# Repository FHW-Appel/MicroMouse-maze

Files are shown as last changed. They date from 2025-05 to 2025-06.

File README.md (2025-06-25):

# Half-Size Micromouse Maze – Projektüberblick

Dieses Projekt beinhaltet die Konstruktion und Fertigung eines Labyrinths (Maze) für ein Half-Size Micromouse-System. Grundlage ist das offizielle Regelwerk der *UK Micromouse and Robotics Society (UKMARS)*, welches in Europa als Standard für Wettbewerbe gilt.

Das Maze besteht aus modularen Zellen (je **9 × 9 cm**), standardisierten Wänden, Pfosten, Bodenplatten und Verbindungselementen. Alle Maße und Farben entsprechen den Vorgaben des UKMARS Half-Size Regelwerks.

Die Konstruktion erfolgte in *Fusion 360*, die einzelnen Komponenten wurden per **3D-Druck** aus PLA gefertigt. Das Maze ist vollständig zerlegbar und kann in unterschiedlichen Layouts aufgebaut werden.

---

## Hinweise zur Nutzung

Das Repository enthält die jeweils **aktuelle Version** aller STL-Dateien. Es werden **keine Versionsnummern** wie `_1.0.stl`, `_2.0.stl` usw. verwendet. Alle Dateien sind direkt einsatzbereit und eindeutig benannt.

### Projektstruktur

- **Bodenplattenmodule/**  
  STL-Dateien für die Bodenplatten, auf denen Wände und Pfosten montiert werden.

- **Stopfenmodule/**  
  STL-Dateien für die Eckpfosten (Blindstopfen), die an den Gitterpunkten zwischen den Zellen eingesetzt werden.

- **Verbindungsmodule/**  
  STL-Dateien für Verbindungselemente zur Fixierung von Bodenplatten und Wänden.

- **Wandmodule/**  
  STL-Dateien für die standardisierten Innenwände des Maze.

- **Projekt-Infos/**  
  Enthält diese Datei (`README.md`) mit allgemeinen Informationen zum Projekt und zur Nutzung.

---

Bei Bedarf können die STL-Dateien direkt in gängige Slicer-Software importiert und für den 3D-Druck vorbereitet werden

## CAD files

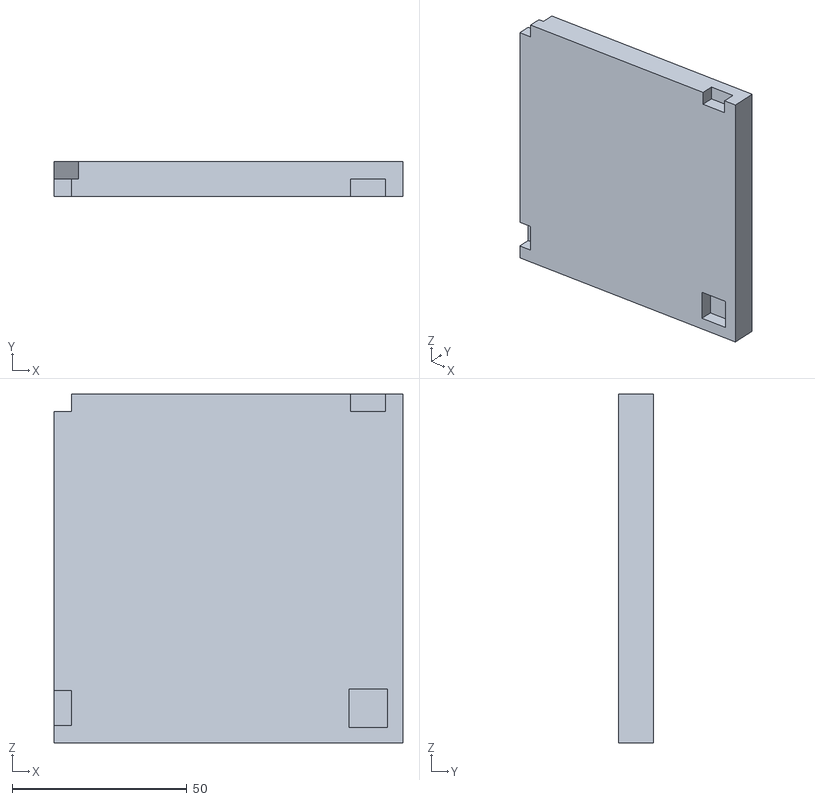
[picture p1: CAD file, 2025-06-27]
Bodenmudule/Boden_Ecke.stl
100.0 x 10.0 x 100.0

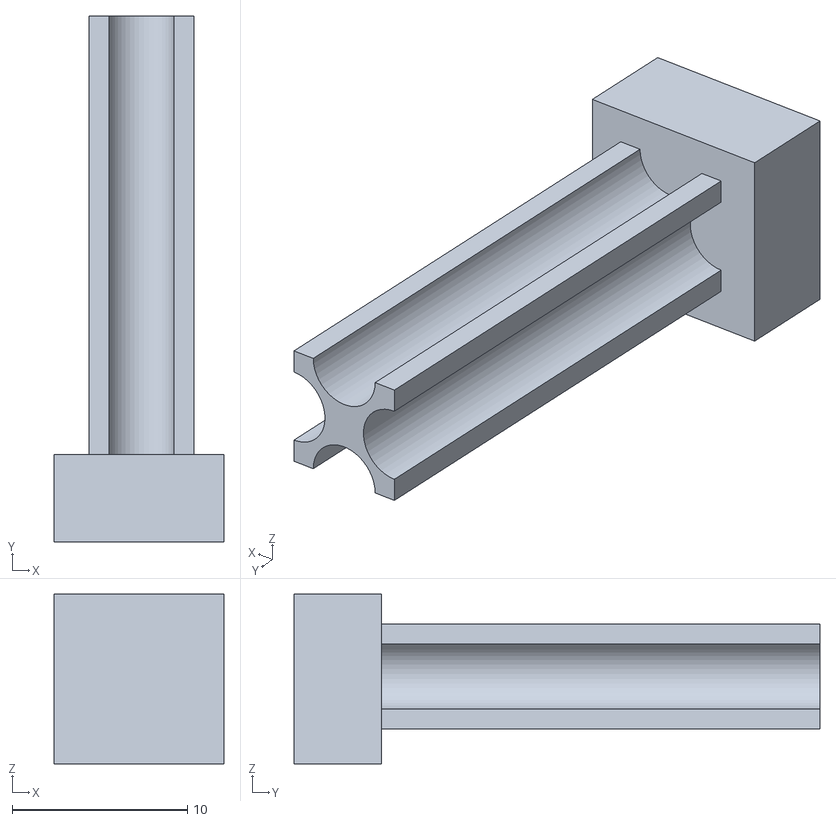
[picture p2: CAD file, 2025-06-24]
Stopfenmodul/Stopfen.stl
9.70 x 30.0 x 9.70

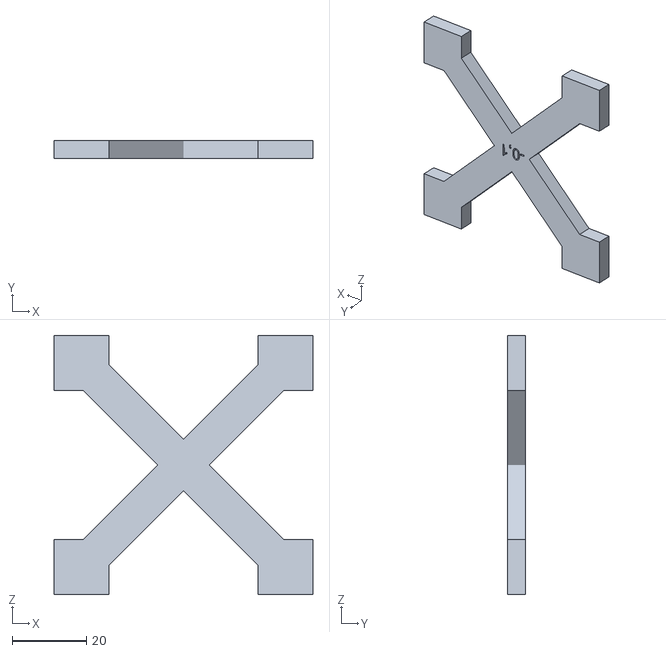
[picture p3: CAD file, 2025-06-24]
Verbindungsmodul/Boden_Kreuzverbindung.stl
69.8 x 4.80 x 69.8

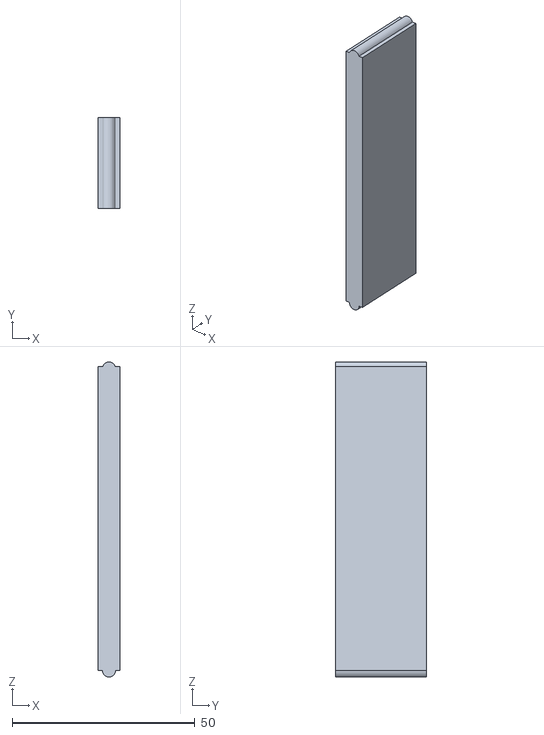
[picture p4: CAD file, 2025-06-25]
Wandmodule/Wand.stl
6.00 x 25.0 x 86.1

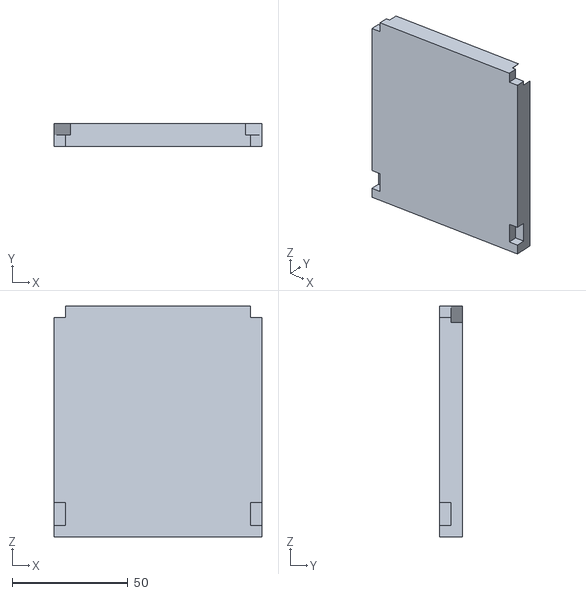
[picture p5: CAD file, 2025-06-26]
Bodenmudule/Boden_Kante.stl
90.0 x 10.0 x 100.0

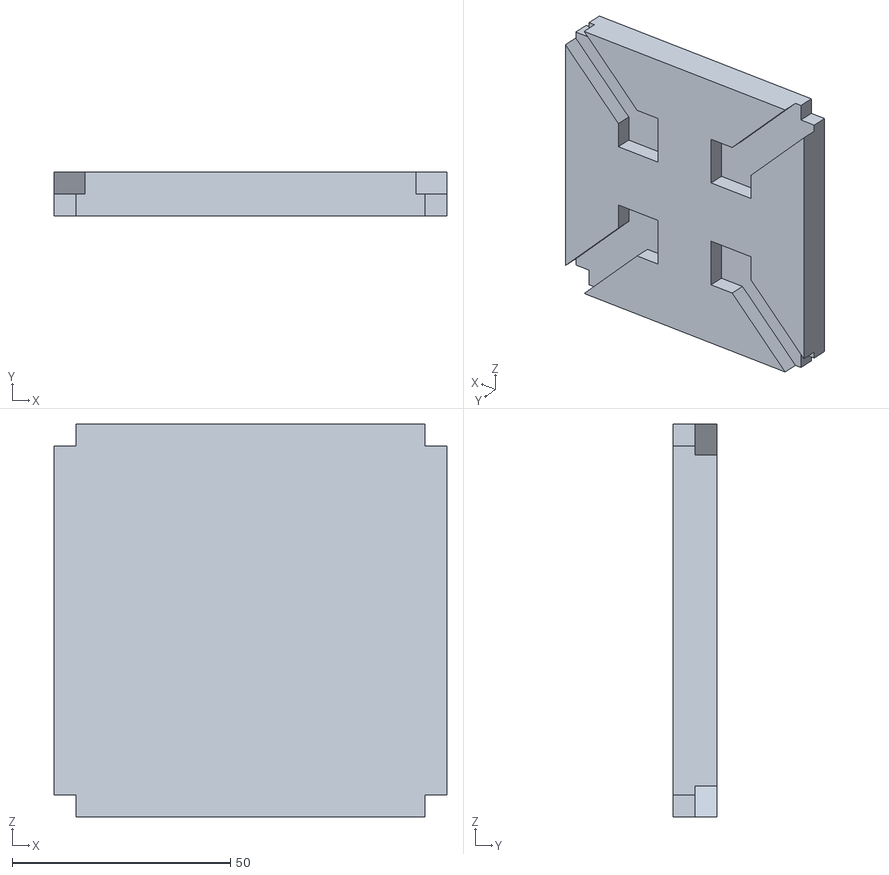
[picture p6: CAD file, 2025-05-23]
Bodenmudule/Boden_Mitte.stl
90.0 x 10.0 x 90.0

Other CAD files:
Bodenmudule/Boden_Ecke.f3d
Bodenmudule/Boden_Kante.f3d
Bodenmudule/Boden_Mitte.f3d
Stopfenmodul/Stopfen.f3d
Verbindungsmodul/Boden_Kreuzverbindung.f3d
Wandmodule/Wand.f3d

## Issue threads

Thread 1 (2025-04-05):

Maze

FHW-Appel, 2025-04-05:
* Half size micro mouse Maße raussuchen und als Anforderungen zusammenschreiben
* Verbindungstechnik Schachbrettkästchen entwickeln und testen
* Verbindungstechnik Wände entwickeln und testen
* Wandmodule
* Blindstopfen entwickeln
* Wand zu Wand Verbindungen
* Repository erstellen

Closed 2025-06-27.

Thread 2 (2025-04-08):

Half size micro mouse Maße raussuchen und als Anforderungen zusammenschreiben

TedeMeyer, 2025-04-08:
Beschreibung:
Für die weitere Planung und Konstruktion unserer Half Size Micro Mouse müssen die genauen Abmessungen (Länge, Breite, Höhe) recherchiert und dokumentiert werden. Ziel ist es, eine realistische und umsetzbare Größenanforderung festzulegen, die sowohl dem Wettbewerbstandard als auch unseren technischen Möglichkeiten entspricht. Die Maße sollen als verbindliche Anforderung festgehalten werden und in die technische Dokumentation einfließen.

Akzeptanzkriterien:

- Verlässliche Quellen zur Definition einer „Half Size Micro Mouse“ wurden recherchiert.
- Die Maße (L/B/H) sind eindeutig in Millimeter angegeben.
- Die Anforderungen wurden in einem separaten Dokument oder Abschnitt innerhalb der Projektdokumentation    festgehalten.
- Das Team hat die Anforderungen überprüft und als realistisch bewertet.

TedeMeyer, 2025-04-23:
## Warum wir uns an die UKMARS Half-Size Micromouse Regeln halten

Für unser Half-Size Micromouse Projekt orientieren wir uns bewusst an den offiziellen Regeln der **UKMARS (UK Micromouse and Robotics Society)**. Diese Regeln sind im europäischen Raum am weitesten verbreitet und bieten eine verlässliche, standardisierte Grundlage für die Entwicklung, das Testen und die Teilnahme an Wettbewerben.

### Vorteile dieser Regelwahl

- **Kompatibilität mit europäischen Wettbewerben**: Durch die Verwendung etablierter Standards können unsere Entwicklungen direkt auf offiziellen Wettbewerben in Europa eingesetzt werden – ohne Anpassungen oder Umbaumaßnahmen.
- **Vergleichbarkeit und Wiederverwendbarkeit**: Ergebnisse, Designs und Softwarelösungen lassen sich besser vergleichen, dokumentieren und austauschen.
- **Technische Klarheit**: Ein einheitliches Regelwerk schafft Transparenz und vereinfacht die Teamarbeit und Kommunikation mit anderen Entwicklern.

---

## Maze-Spezifikationen gemäß UKMARS Half-Size Regelwerk

Das Labyrinth (Maze), in dem der Micromouse fährt, ist präzise definiert:

### Zellenstruktur

- Das Maze besteht aus **9 cm × 9 cm** großen Einheiten.
- Die Gesamtgröße beträgt maximal **32 × 32 Zellen**.

### Wandgestaltung

- **Seitenwände**: weiß
- **Oberseite der Wände**: rot
- **Bodenfläche**: schwarz, mit matter Farbe oder Lack gestrichen
- **Wandhöhe**: 2,5 cm
- **Wanddicke**: 0,6 cm
- **Durchgangsbreite**: 8,4 cm

### Startfeld

- Liegt in einer der **vier Ecken** des Labyrinths.
- Umgeben von **drei Wänden**.
- Die offene Seite zeigt nach **Norden**.
- Außenwände befinden sich dabei auf der **West- und Südseite**.
- Startausrichtung erfolgt **im Uhrzeigersinn**.

### Zielbereich (End Point)

- Der Zielbereich ist ein **rechteckiger Bereich** aus mehreren Zellen.
- Position und Größe werden **vor dem Wettbewerb** bekanntgegeben.
- Der Bereich wird über zwei **diagonal gegenüberliegende Koordinaten** definiert.
- Nur im Zentrum dieses Bereichs darf sich **kein Wandanschluss an einem Gitterpunkt** befinden.

### Gitterpunkte und Pfosten

- An jeder Zellenecke (Gitterpunkt) befindet sich ein **Pfosten**:
  - Maße: **0,6 cm × 0,6 cm × 2,5 cm (Höhe)**
- An **jedem Gitterpunkt** muss mindestens eine Wand anschließen – außer im Zentrum des Zielbereichs.
- **Alle Außenwände** des Labyrinths sind vollständig vorhanden.

---

Diese Spezifikationen ermöglichen eine konsistente und professionelle Umsetzung unseres Projekts und sichern die Kompatibilität mit dem internationalen Wettbewerbssystem.

NikolasFHW, 2025-04-25:
Es wurden die **europäischen Regelungen** herangezogen, um eine praxisnahe Teilnahme zu gewährleisten, deren Prinzipien sich auf den gesamten europäischen Raum übertragen lassen.

NikolasFHW, 2025-04-25:
Das erste Issue der Gruppe wurde erfolgreich abgeschlossen und in die Spalte _Done_ verschoben. Die Funktionsweise von GitHub-Issues wurde verstanden und wird zukünftig korrekt angewendet.

Closed 2025-04-25.

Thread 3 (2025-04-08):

Verbindungstechnik Schachbrettkästchen entwickeln und testen

NikolasFHW, 2025-04-08:
Ziel der Aufgabe ist es, eine praktikable Verbindungstechnik für die modularen Schachbrettkästchen des Micro-Maus-Maze zu entwickeln und zu testen. Die Verbindung soll stabil, einfach handhabbar und ohne Werkzeug auf- und abbaubar sein. Abschließend soll die gewählte Lösung dokumentiert und dem Team zur Verfügung gestellt werden.

**Akzeptanzkriterien:**

-  Mindestens ein getesteter Prototyp funktioniert zuverlässig in mehreren Auf- und Abbauzyklen
-  Die Verbindung hält die Kästchen auch bei leichtem Anstoßen stabil zusammen
-  Die Kästchen können ohne Werkzeug verbunden und wieder gelöst werden
-  Eine verständliche Anleitung oder Skizze zur Verbindungstechnik liegt dem Team vor

NikolasFHW, 2025-04-23:
Verbindungssystem im Schachbrettmuster:
An jeder Ecke eines Boden-Kästchens ist eine Aussparung vorgesehen, in die ein Verbindungselement eingesetzt wird. Diese Verbindung hat die Form eines Kreuzes mit vier Armen, an deren Enden sich jeweils ein dreieckiger Kopf befindet. Die Dreiecke greifen in die angrenzenden Aussparungen der vier umliegenden Bodenplatten ein.

Der Mittelpunkt des Kreuzes liegt dabei exakt im Zentrum eines Quadrats, das durch vier benachbarte Bodenplatten gebildet wird. Die Bodenplatten verfügen an diesen Stellen über entsprechende Ausparungen, sodass das Kreuz bündig und stabil integriert werden kann.

In der Mitte des Verbindungskreuzes befindet sich zudem eine zusätzliche, runde Aussparung. Diese dient als Aufnahmepunkt für einen Stopfen, der je nach Anwendung bündig abschließt oder zur weiteren Befestigung (z. B. eines Moduls) verwendet wird.

NikolasFHW, 2025-04-25:
Am 25.04 wurden erste Druckversuche gestartet mit Bodenplatten jeweils 10x10 cm. Dies ist fehlgeschlagen und die Platten werden kleiner gestaltet, aktueller Entwurf ist eine 5x5 cm Platte. Diese müssen gedruckt und auf weitere Kompatibilität mit den Stopfen geprüft.

NikolasFHW, 2025-05-07:
Am 28.04. wurde der 5 × 5 cm große Plattendruck erfolgreich fertiggestellt und anschließend geprüft. Dabei zeigte sich, dass die vorgesehenen Toleranzen zu gering ausgelegt waren. Infolgedessen kam es an der Kreuzverbindung der Platten zu einem Anschlagen bzw. Verkannten.

NikolasFHW, 2025-05-09:
Am 07.05. wurde der neue Entwurf gedruckt. Die neuen Platten haben jeweils ein Maß von 9 × 9 cm und wurden mit unterschiedlichen Steckverbindungen gefertigt, die Toleranzen von 1 mm, 1,5 mm, 2 mm und 2,5 mm aufweisen. Dabei hat sich gezeigt, dass die 1-mm-Toleranz am besten funktioniert und die höchste Formstabilität bietet. Daher wird diese Toleranz für die weitere Umsetzung beibehalten.

NikolasFHW, 2025-05-16:
Aktuelle Idee für die Außenwände: Für die Außenwände werden spezielle Bodenplatten verwendet, die nach außen hin verlängert sind. Dadurch ist keine zusätzliche Bodenplatte erforderlich, um den Platzhalter für den Stopfen vollständig auszubilden. Dieses Konzept ermöglicht den einheitlichen Einsatz desselben Stopfens sowie desselben Wandmoduls für Innen- und Außenbereiche.

FHW-Appel, 2025-05-16:
Bitte unter Code auch die f3d Dateien ablegen.

NikolasFHW, 2025-06-25:
Zur modularen und stabilen Verbindung der Bodenplatten des Half-Size-Micromouse-Maze wurde eine sogenannte Schachbrett-Verbindungstechnik entwickelt. Grundlage dieser Technik ist ein zentrales Kreuzelement, das unter den Bodenplatten positioniert wird. Dieses Kreuz verfügt an jedem Ende über eine pfeilförmige Ausparung, die der Aufnahme von Verbindungsstopfen dient und so für strukturellen Halt sorgt.

Jede Bodenplatte besitzt an ihren Ecken entsprechende Ausparungen zur Aufnahme der Stopfen. Es wurden drei unterschiedliche Typen von Bodenplatten konstruiert, jeweils angepasst an ihre Position im Gesamtsystem:

Mittlere Platten:

Format: 90 mm × 90 mm

An jeder Ecke eine ¼-Ausparung für den Blindstopfen

Werden rundum mit anderen Platten verbunden

Kantenplatten:

Format: 90 mm × 90 mm

Innen Ecken mit ¼-Ausparung, außen je eine ½-Ausparung, da dort nur ein Gegenstück vorhanden ist

Eckplatten:

Format: 100 mm × 100 mm

Innen Ecke mit ¼-Ausparung, an den Kanten je eine ½-Ausparung, da dort nur ein Gegenstück vorhanden ist
Enthalten eine vollständige Blindstopfen-Aussparung in der Ecke.

Diese Konstruktion ermöglicht einen flexiblen, stabilen und maßhaltigen Aufbau des Maze, der exakt den Anforderungen des Half-Size-Micromouse-Standards entspricht. Die entwickelte Technik wurde erfolgreich getestet und in das finale System übernommen.

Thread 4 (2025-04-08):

(Außen/Innen-)Wände Verbindungstechnik entwickeln und testen

NikolasFHW, 2025-04-08:
Für den Aufbau des Micro-Maus-Maze soll eine Verbindungstechnik entwickelt werden, mit der sich die einzelnen Schachbrettkästchen stabil und wieder lösbar miteinander verbinden lassen. Die Verbindung soll werkzeuglos funktionieren und den Aufbau des Labyrinths erleichtern. Nach der Erprobung verschiedener Konzepte wird die beste Lösung ausgewählt und dokumentiert.

**Akzeptanzkriterien:**

**DAS ISSUE WURDE VOLLSTÄNDIG VERWORFEN, alle Wände sind gleich, es ist keine spezielle Verbindung nötig.**
- Mindestens ein getesteter Prototyp funktioniert zuverlässig in mehreren Auf- und Abbauzyklen
- Die Verbindung hält die Kästchen auch bei leichtem Anstoßen stabil zusammen
- Die Kästchen können ohne Werkzeug verbunden und wieder gelöst werden
- Eine verständliche Anleitung oder Skizze zur Verbindungstechnik liegt dem Team vor

NikolasFHW, 2025-04-23:
**Anforderungen an die Wandverbindungstechnik:**
Die **Innenwände** unterliegen den Vorgaben des Issues „Wand-zu-Wand-Verbindung“, insbesondere hinsichtlich der modularen Verbindungstechnik. Die Befestigung erfolgt dabei über herausstehende Blindstopfen mit dreieckigen Aufnahmen, in die die Wandmodule formschlüssig eingesteckt werden.

Für die **Außenwände** sieht der aktuelle Entwurf hingegen eine starre, dauerhaft fixierte Verbindung vor. Diese soll fest und belastbar sein – beispielsweise durch Verschraubung oder Verklebung.

Gleichzeitig müssen die Außenwände über eine geeignete Steckverbindung verfügen, um eine einfache und sichere Montage der Innenwände zu ermöglichen. Die Kompatibilität zur modularen Verbindungstechnik der Innenwände muss dabei gewährleistet bleiben.

NikolasFHW, 2025-04-23:
**Verbindungslogik der Wandmodule und Blindstopfen:**

Der herausstehende Blindstopfen besitzt grundsätzlich den weiblichen Part der Verbindung. Das bedeutet, dass die Wandmodule stets den männlichen Gegenpart tragen, der in die dreieckigen Aufnahmen des Blindstopfens eingesteckt wird.

Eine Ausnahme bilden die Außenwände:
Da diese selbst die Funktion eines Blindstopfens übernehmen, besitzen sie in diesem Fall den weiblichen Part der Verbindung. Die Außenwand agiert somit als passive Aufnahme, in die ein männliches Verbindungselement – etwa von einem Innenwandmodul – eingeschoben werden kann.

NikolasFHW, 2025-05-16:
Der aktuelle Entwurf sieht vor, dass Außen- und Innenwände identisch konstruiert werden. Die Bodenplatten werden dabei entsprechend erweitert, sodass der Stopfen sicheren Halt findet, ohne dass zusätzliche Bodenplatten nach außen notwendig sind. Dadurch kann für Innen- und Außenwände ein einheitliches, universell einsetzbares Modell verwendet werden.

NikolasFHW, 2025-06-25:
Im Verlauf der Entwicklung wurde entschieden, die ursprüngliche Unterscheidung zwischen Außen- und Innenwänden aufzugeben. Statt zwei separaten Wandtypen existiert nun nur noch ein einheitliches Wandmodul, das für sämtliche Positionen im Maze verwendet wird.

- Diese Vereinheitlichung bringt mehrere Vorteile mit sich:
- Reduzierte Komplexität in Konstruktion, Lagerung und Handhabung
- Einheitliches Verbindungssystem, das unabhängig vom Wandtyp funktioniert
- Vereinfachte Produktion durch nur ein 3D-Druckmodell
- Minimierter Material- und Zeitaufwand

Aufgrund dieser Entscheidung entfällt die Notwendigkeit, eine separate Verbindungstechnik

Closed 2025-06-27.

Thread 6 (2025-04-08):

Blindstopfen-Alternative entwickeln

NikolasFHW, 2025-04-08:
Für nicht benötigte Öffnungen oder Anschlüsse im Micro-Maus-Maze soll eine Alternative zu herkömmlichen Blindstopfen entwickelt werden. Ziel ist es, eine kostengünstige, einfach einsetzbare und gegebenenfalls wieder verwendbare Lösung zu finden, die zuverlässig abdichtet oder abdeckt. Die entwickelte Alternative soll getestet und dokumentiert werden.

**Akzeptanzkriterien:**

- Die Lösung verschließt Öffnungen sicher und verrutscht nicht bei Erschütterung oder Bewegung
- Der Einbau und Ausbau ist ohne spezielles Werkzeug möglich
- Die Alternative ist kostengünstig und mit gängigen Mitteln (z. B. aus dem Baumarkt oder 3D-Druck) realisierbar
- Eine Skizze oder Anleitung zur Umsetzung liegt dem Team vor

NikolasFHW, 2025-04-23:
Eine mögliche Variante ist ein Hybridmodell.
Dabei wird im Boden kein Blindstopfen benötigt. Stattdessen ist in der Steckverbindung des Bodens eine Aussparung vorgesehen. Diese Aussparung befindet sich mittig in der Verbindung und jeweils an den Ecken der einzelnen Bodenplatten.

Es gibt zwei Varianten von Blindstopfen:
Ein herausstehender Blindstopfen, an dem bei Bedarf ein Wandmodul befestigt werden kann, sowie ein bündiger Blindstopfen, der mit der Oberfläche der Bodenplatten abschließt. Letzterer sorgt dafür, dass kein Hindernis entsteht, falls kein Wandmodul verwendet wird.

NikolasFHW, 2025-04-23:
**Variante Hybridmodell:**

Es gibt zwei Arten von Blindstopfen:

Der bündige Blindstopfen wird in ein rundes Loch eingesetzt und schließt eben mit der Oberfläche der Bodenplatten ab. So entsteht keine Stolperkante, wenn kein Wandmodul erforderlich ist.

Der herausstehende Blindstopfen dient zur Befestigung eines optionalen Wandmoduls. Er ist so konstruiert, dass er in Richtung jeder Fuge der Bodenplatten eine dreieckige Aufnahme aufweist – insgesamt also vier Dreieckaufnahmen pro Stopfen. In diese kann das Wandmodul eingeschoben werden.

Die besondere Form – ein „umgekehrtes Dreieck“ – verhindert, dass das Wandmodul nach außen herausfallen kann. Es kann nur nach oben entnommen oder von oben eingesetzt werden, was für eine sichere Verbindung sorgt.

NikolasFHW, 2025-04-23:
Zusätzlicher Blindstopfen zur Lückenschließung bei Außenwänden:
Für den Fall, dass an einer Außenwand keine Innenwand anschließt, entsteht eine konstruktionsbedingte Lücke, die geschlossen werden muss. Zu diesem Zweck wird ein zusätzlicher Blindstopfen benötigt, der diese Lücke ausfüllt und das äußere Erscheinungsbild sowie die Stabilität sicherstellt.

Da in diesem Bereich keine gegenliegende Wand als Halteelement vorhanden ist, besteht die Gefahr, dass der Blindstopfen herausfallen könnte. Zur Sicherung ist daher aktuell die Verwendung eines sogenannten „Splints“ vorgesehen. Dieser wird über die Außenwand hinweg nach außen geführt und fixiert den Blindstopfen, indem er die Lücke zuverlässig verschließt.

NikolasFHW, 2025-04-23:
**Verbindungslogik der Wandmodule und Blindstopfen:**

Der herausstehende Blindstopfen besitzt grundsätzlich den weiblichen Part der Verbindung. Das bedeutet, dass die Wandmodule stets den männlichen Gegenpart tragen, der in die dreieckigen Aufnahmen des Blindstopfens eingesteckt wird.

**Eine Ausnahme bilden die Außenwände:**
Da diese selbst die Funktion eines Blindstopfens übernehmen, besitzen sie in diesem Fall den weiblichen Part der Verbindung. Die Außenwand agiert somit als passive Aufnahme, in die ein männliches Verbindungselement – etwa von einem Innenwandmodul – eingeschoben werden kann.

NikolasFHW, 2025-04-25:
Kurzes Zwischenupdate zur Zusammenfassung:
**Es wurde sich entgegen des Issue Titels FÜR ein Blindstopfen entschieden**

NikolasFHW, 2025-05-09:
Es gibt eine neue Idee für die Gestaltung eines Blindstopfens: Dieser soll möglicherweise als Bajonettverschluss ausgeführt werden. Diese Variante würde eine deutlich höhere Stabilität bieten, allerdings führt sie auch zu einer stärkeren mechanischen Belastung der Bauteile, da der Bajonettverschluss vergleichsweise klein dimensioniert ist.

FHW-Appel, 2025-05-16:
Bitte unter Code auch die f3d Dateien ablegen.

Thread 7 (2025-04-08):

(Innenwände) Wand-zu-Wand-Verbindungen entwickeln und testen

TedeMeyer, 2025-04-08:
Beschreibung:
Für den modularen Aufbau des Parcours mit Wandmodulen müssen zuverlässige und leicht montierbare Verbindungen zwischen den Wänden entwickelt werden. Ziel dieses Issues ist es, verschiedene Verbindungsmöglichkeiten (z. B. Stecksysteme, Clips, Magnetverbindungen) zu recherchieren, eine passende Lösung auszuwählen und ein eigenes Verbindungssystem als 3D-Modell zu entwerfen. Anschließend soll das System im 3D-Druckverfahren erstellt, getestet und optimiert werden. Die Verbindung soll stabil, leicht lösbar und wiederverwendbar sein und präzise Ausrichtung der Wände ermöglichen.

Akzeptanzkriterien:

- Es wurde ein Verbindungskonzepte recherchiert: Siehe verlauf, finale Version im Wiki.
- Anforderungen an das Verbindungssystem wurden definiert: Stabilität, Wiederverwendbarkeit und Toleranzen, alles erfüllt die Anforderungen
- Ein CAD-Modell für das gewählte Verbindungssystem wurde erstellt und Dokumentiert: Siehe Repository.
- Die Verbindung wurde 3D-gedruckt, mit Wandmodulen getestet und auf Passgenauigkeit sowie Stabilität geprüft: Siehe Labor

Evidence

Das Verbindungssystem wurde erfolgreich entwickelt und getestet. Es erfüllt alle definierten Anforderungen an Stabilität, Wiederverwendbarkeit und Passgenauigkeit. Das CAD-Modell ist dokumentiert, die finale Version wurde gedruckt und mit den Wandmodulen im Labor geprüft. Ergebnisse und Unterlagen sind im Repository und Wiki hinterlegt.

NikolasFHW, 2025-04-23:
**Verbindungslogik der Wandmodule und Blindstopfen:**

Der herausstehende Blindstopfen besitzt grundsätzlich den weiblichen Part der Verbindung. Das bedeutet, dass die Wandmodule stets den männlichen Gegenpart tragen, der in die dreieckigen Aufnahmen des Blindstopfens eingesteckt wird.

Eine Ausnahme bilden die Außenwände:
Da diese selbst die Funktion eines Blindstopfens übernehmen, besitzen sie in diesem Fall den weiblichen Part der Verbindung. Die Außenwand agiert somit als passive Aufnahme, in die ein männliches Verbindungselement – etwa von einem Innenwandmodul – eingeschoben werden kann.

FHW-Appel, 2025-05-14:
Die Wand-zu-Wand Verbinder könnten zusammen mit der Verbindungstechnik für die Schachbrettkästchen einen Verriegelungsmechanismus bilden mit dem die Schachbrettkästchen gehalten werden.

Closed 2025-06-27.

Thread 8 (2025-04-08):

Repository erstellen

NikolasFHW, 2025-04-08:
Für die zentrale Verwaltung aller projektbezogenen Dateien und Quellcodes soll ein Repository erstellt werden. Es dient als gemeinsame Arbeitsplattform für das Team, um Änderungen nachverfolgbar zu machen, die Zusammenarbeit zu erleichtern und die Projektstruktur sauber zu halten. Das Repository soll initial eingerichtet und strukturiert werden.

**Akzeptanzkriterien:**

- Ein Repository wurde erfolgreich auf GitHub erstellt [x]: Siehe GitHub "Code"
- Die grundlegende Ordnerstruktur ist angelegt [x]: Alle benötigten Module, siehe Repository
- Eine Datei mit kurzem Projektüberblick und Hinweisen zur Nutzung ist vorhanden [x]: Projekt-Infos.txt
- Zugriffsrechte für alle Teammitglieder sind eingerichtet[x]: Alle Mitglieder können zugreifen

NikolasFHW, 2025-05-14:
Ein Repository wurde erfolgreich erstellt und mit der Desktop-Anwendung verbunden, sodass Änderungen problemlos vorgenommen werden können.

Zur besseren Organisation wurde eine grundlegende Ordnerstruktur angelegt. Diese orientiert sich an den vorhandenen Issues und ist modular aufgebaut: Für jedes Modul wurde ein eigener Ordner erstellt. In diesen Ordnern können künftig die verschiedenen Versionen aus Fusion abgelegt werden.

Zudem wurde eine Info-Textdatei zur allgemeinen Projektbeschreibung erstellt. Diese muss jedoch noch mit den entsprechenden Inhalten und Informationen zum Projekt ergänzt werden.

NikolasFHW, 2025-05-16:
Zur Unterstützung steht eine Datei bereit, die einen kompakten Überblick über das Projekt liefert und zusätzlich wichtige Hinweise zur Nutzung der enthaltenen Inhalte bietet. Sie dient als Einstiegshilfe und Orientierung für alle Beteiligten.

NikolasFHW, 2025-05-16:
Alle Projektmitglieder verfügen über Zugriff auf das Repository und können bei Bedarf jederzeit auf die darin enthaltenen Daten und Dateien zugreifen.

FHW-Appel, 2025-05-16:
Die Projekt-Infos.txt bitte noch in README.md umbenennen, dann wird diese Datei auch direkt beim Aufruf des Repositories angezeigt.

Closed 2025-05-23.

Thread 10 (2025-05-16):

Fertiges Maze testen

TedeMeyer, 2025-05-16:
Beschreibung:
Ziel dieses Tests ist es, sicherzustellen, dass das gebaute Half-Size-Maze funktional ist und stabil genug für den Einsatz mit einer Micro Mouse. Es soll überprüft werden, ob alle Verbindungen korrekt sind, keine Lücken zwischen den Wänden bestehen und die Struktur robust genug ist, um leichten Kollisionen standzuhalten.

Testbeschreibung:

- Das komplette Maze wird aufgebaut.
- Sichtprüfung auf saubere, feste Wandverbindungen
- Leichtes Drücken gegen Wände simuliert Micro-Mouse-Kollisionen.
- Eine Micro Mouse wird vorsichtig durch das Maze geschoben, um reale Belastung zu simulieren.
- Überprüfung, ob Wände während des Tests verrutschen oder sich lösen.

Akzeptanzkriterien:

 - Alle Wandverbindungen sind stabil und fest
 - Keine unerwünschten Lücken zwischen Wandteilen oder Modulen.
 - Das Maze bleibt auch bei leichten Stößen durch die Micro Mouse strukturell stabil.
 - Alle Segmente sitzen korrekt im Grid, sodass Navigation ohne physische Barrieren möglich ist.
 - Es gibt keine herausstehenden Kanten, an denen die Micro Mouse hängen bleiben könnte.
 - Der Testlauf mit einer Micro Mouse oder durch manuelles Schieben war erfolgreich ohne Umbauten.

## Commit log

2025-05-14 Erste Innenwandmodelle+passender Stopfenverbindung
    Das erste Innenwandmodul besitzt die Abmessungen 25 mm × 6 mm × 100 mm. Am Ende dieses Moduls befindet sich eine halbkreisförmige Ausformung mit einem Radius von 1,75 mm.
    Der dazugehörige Blindstopfen ist quaderförmig mit einer Grundfläche von 6 mm × 6 mm. An allen vier Seiten des Blindstopfens befindet sich jeweils eine halbkreisförmige Aussparung mit einem Radius vo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
    [Stopfen_1.0.stl, Wand_1.0.stl]
2025-05-14 Übersichtlichkeit
    Übersichtlichkeit -> Löschen von LICENSE und README
2025-05-14 Ordnerstruktur
    Es wurde eine Ordnerstruktur erstellt, die auf den Issues aufbaut.
    [Stopfen_1.0.stl, Wand_1.0.stl]
2025-05-16 Neue Module (V2)
    Ein neues Wandmodul und ein Stopfenmodul, beide Version 2
    [Stopfen_2.0.stl, Wand_2.0.stl]
2025-05-16 Projekt-Infos-Datei
    Die txt. Datei mit den Projekt Infos wurde hinzugefügt.
    [Stopfen_1.0.stl, Stopfen_2.0.stl, Wand_1.0.stl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]
2025-05-20 README hinzugefügt
    Die Datei Projekt-Infos wurde in README umbenannt, damit diese in der Vorschau angezeigt wird.
2025-05-21 f3d Dateien
    Hinzufügen f3d Dateien und neues Stopfenmodul
    [Stopfen_1.f3d, Stopfen_2.f3d, Stopfen_3.0.stl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]
2025-05-23 Bodenmodule hinzugefügt
    Wir haben verschiedene Bodenmodule entwickelt, die sich in drei Kategorien unterteilen: Innenmodule, Außenmodule und Eckmodule. Ergänzend dazu wurde eine passende Steckverbindung integriert, um eine 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
    [MM_Floor_Center_V1.stl, MM_Floor_Corner_V1.stl, MM_Floor_Cross_V1.stl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]
2025-06-06 Änderung der Namen und Versionen
    Die Ordner wurden nun reduziert und es liegt jeweils nur noch die neuste Version im Code. Außerdem wurden die Namen der erstellten Dateien entfernt, da diese jetzt nicht mehr benötigt werden.
    [MM_Floor_Center.stl, MM_Floor_Corner.stl, MM_Floor_Cross.stl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]
2025-06-06 Fusion-Datei umbenannt
    Da ich die alle Dateien umbenannt hatte, musste ich diese ebenso umbenennen, weil ich diese vergessen hatte.
    [Maze_Alle_Module.f3d]
2025-06-13 Wand überarbeitet
    Die Wand wurde überarbeitet und auf die hoffentlich richtige Länge Konstruiert.
    [Wand.f3d, Wand.stl]
2025-06-24 Neu Versionen
    Diverse neue Versionen von Bodenplatten und Verbindungsmodulen
    [Bodenplatte_1.f3d, Bodenplatten_1.0.stl, Verbindungsmodul_1.0.stl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]
2025-06-24 Aktualisierte Module
    Alle eingefügten Module sind jetzt die finalen Versionen.
    [Boden_Ecke.f3d, Boden_Ecke.stl, Boden_Kante.f3d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]
2025-06-25 Finale Wand
    [Wand.f3d, Wand.stl]
2025-06-25 Finale Stopfen
    [Stopfen.f3d]
2025-06-25 Finale Boden_Ecke und -_Kante Versionen
    [Boden_Ecke.f3d, Boden_Ecke.stl, Boden_Kante.f3d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]
2025-06-26 Finale Form
    [Boden_Ecke.f3d, Boden_Ecke.stl, Boden_Kante.f3d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]
2025-06-27 Mini Fixes
    [Boden_Ecke.f3d, Boden_Ecke.stl]
